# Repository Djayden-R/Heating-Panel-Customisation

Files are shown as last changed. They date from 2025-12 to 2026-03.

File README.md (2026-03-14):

# Heating-Panel-Customisation

This ESP-based device is an upgrade for a heating panel that lacks a thermostat, it will switch off the panel once it reaches the correct temperature. And all that in a formfactor of 5,8 x 2,9 x 3,3 cm (excl. the clip on the bottom).

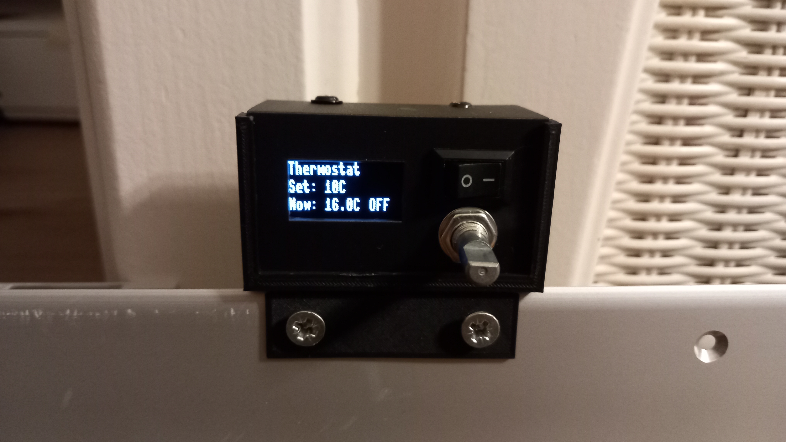
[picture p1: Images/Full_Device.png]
Device frontview


## Why did I make it?

My parents asked me if I could make something that would automatically turn off a heating panel if it reached a certain temperature. So that is what I set out to make.

## How does it work

The device consists of an ESP, a relay, and a temperature sensor. And for user input it also has a switch for turning the device on and off, a rotary encoder for setting the temperature, and an LCD showing the current temperature, set temperature and status. The wiring can be seen below.

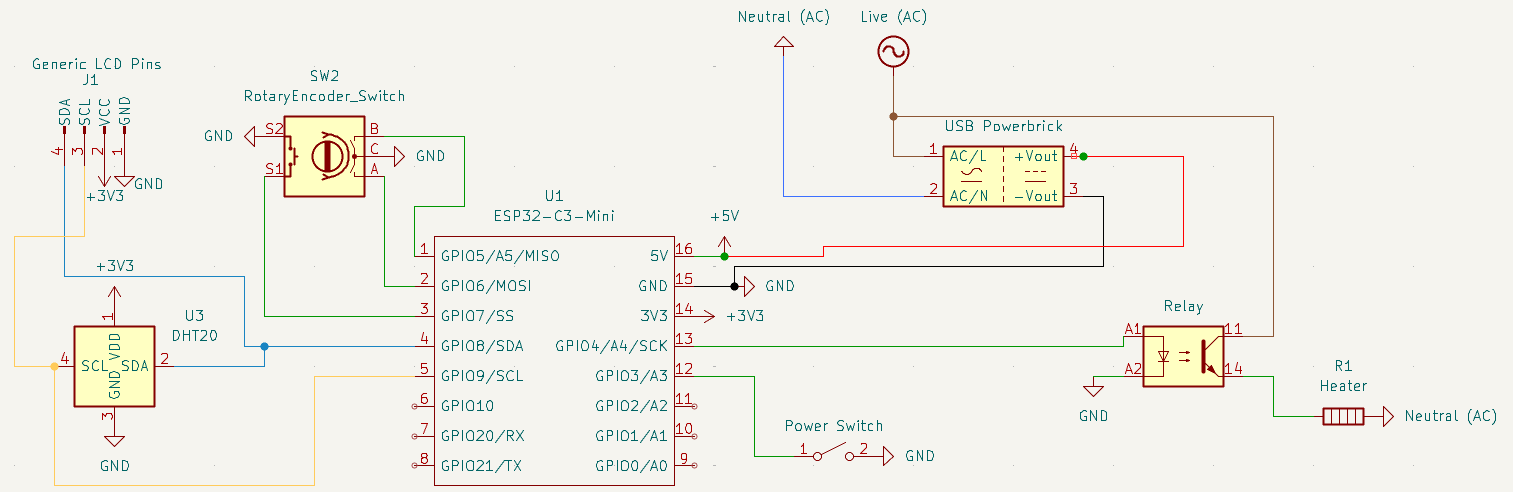
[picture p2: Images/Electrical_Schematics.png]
Wiring schematic


The ESP will sense the temperature in the room and turn on a relay that is connected to the heater if it is under the requested temperature. The ESP is powered from a USB powerbrick inside the heating panel. I also made a schematic with pictures of the components, but the wiring isn't that clear.

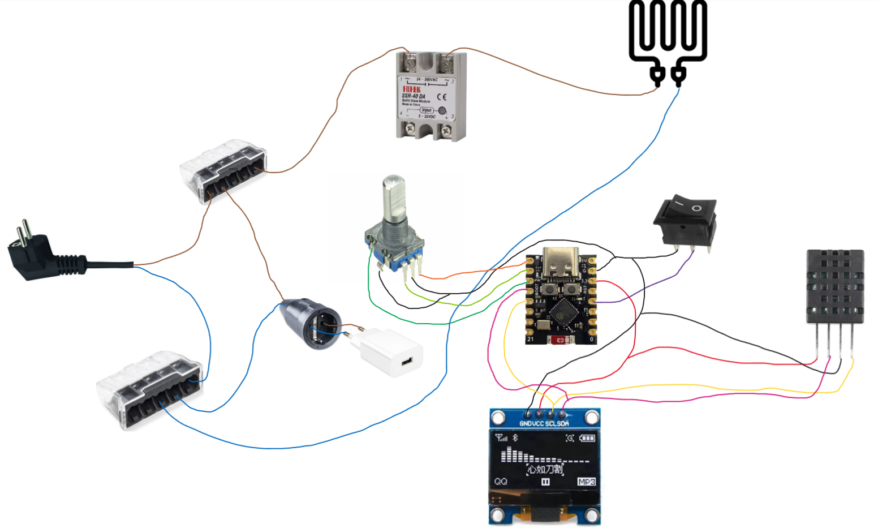
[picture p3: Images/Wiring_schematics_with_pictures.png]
Witing with pictures


The device's clip (see image below) can be placed on the ridge of the heating panel and be secured with bolts. There will have to be a hole drilled in the heating panel, through which the charging cable and cabel for the relay will be placed.

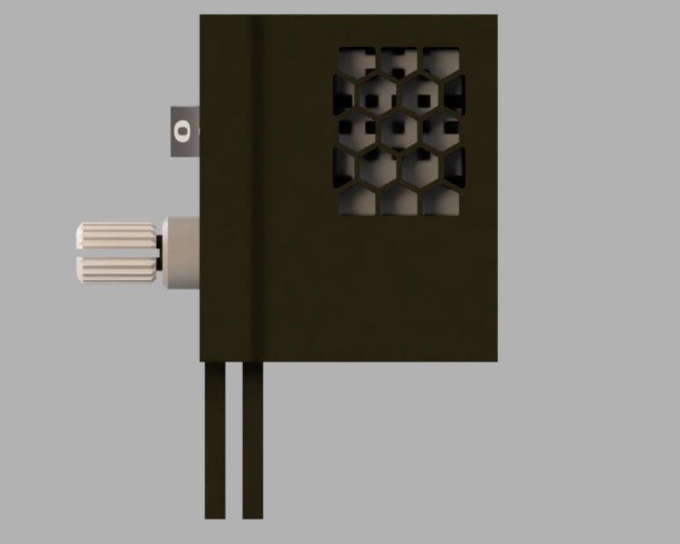
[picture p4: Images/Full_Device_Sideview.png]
Sideview of device

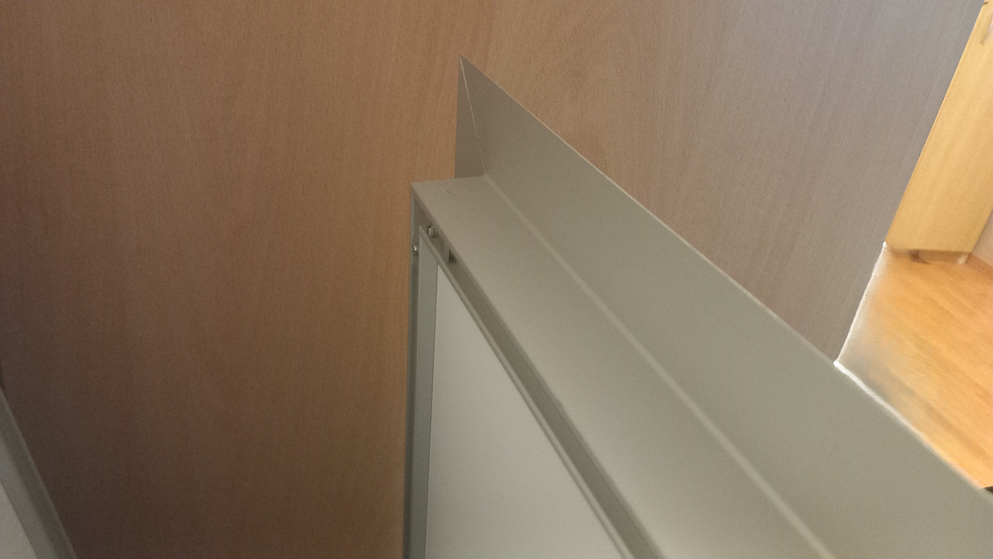
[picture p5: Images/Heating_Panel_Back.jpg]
Heating panel's ridge


I have made a short video demonstrating the finished project, you can find it [here](https://www.youtube.com/watch?v=DKDE-mrpqO4)

## How to assemble the device

Below is a GIF showing the process of putting the device together. Some steps are left out, like installing the outlet, connecting the ESP to it, connecting the relay inside the heating panel and to the ESP.

Assembly Instruction

## How to install firmware

The firmware is made for a micropython device, so if your device doesn't have micropython yet you should install that first.

To install the firmware use a program like Thonny IDE and upload all of the files ending in ```.py``` inside the Firmware folder and rename ```Device.py``` to main.py

The program should then just run on boot.

Also sidenote, the whole ```Device.py``` code is AI-generated, so if you are curious to see how it works you can take a look at it, but you won't find anything interesting.

## BOM

> USD prices are at the time of writing, use  a currency converter for more accurate USD prices

| Item | Description | Amount | Already owned | Cost (€) | Cost (US$) | URL | Image |
|---|---|---|---|---|---|-----|---|
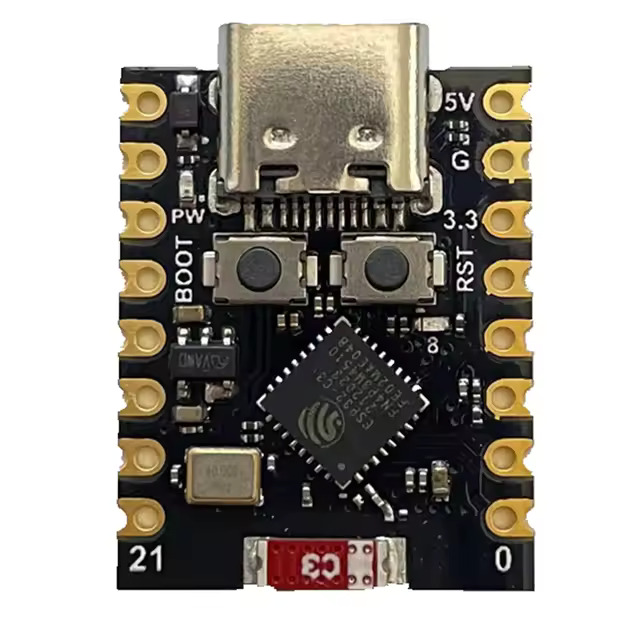
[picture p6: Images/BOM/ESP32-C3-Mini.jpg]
ESP32 C3 Mini
| ESP32 C3 Mini | ESP module | 1 | no | 2.99 | 3.52 | <https://nl.aliexpress.com/item/1005010612626337.html> |  |
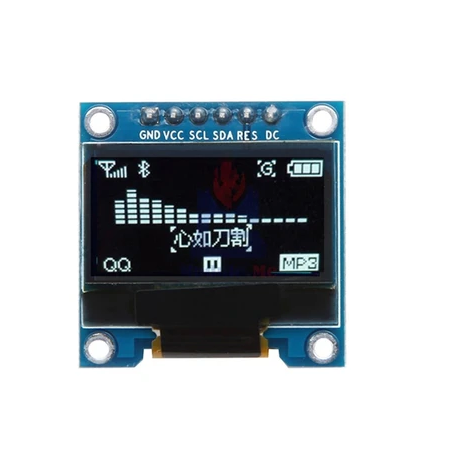
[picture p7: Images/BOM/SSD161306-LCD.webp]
LCD Screen
| SSD1306 LCD | 4 pin serial LCD | 1 | no | 2.10 | 2.47 | <https://nl.aliexpress.com/item/1005010446208996.html> |  |
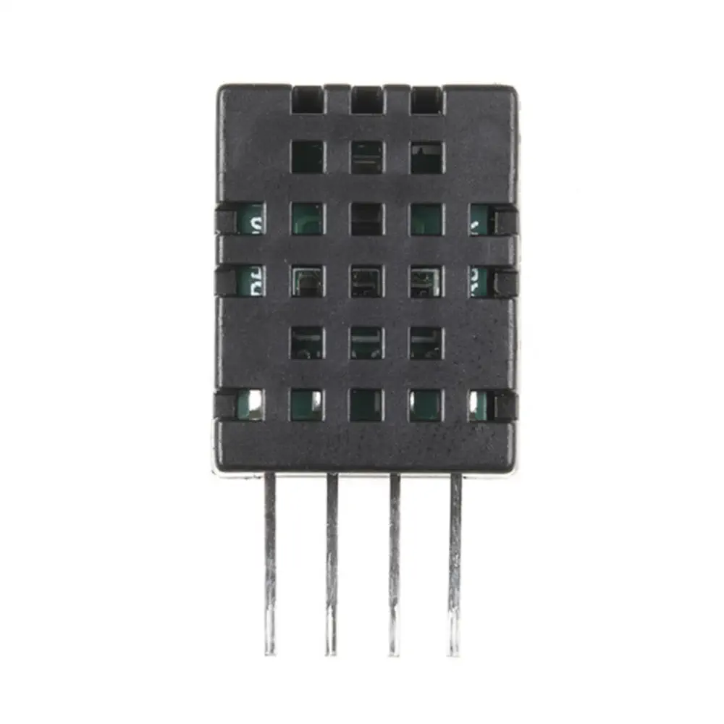
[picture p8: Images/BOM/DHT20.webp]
DHT20
| DHT20 Sensor | Temperature and humidity sensor | 1 | no | 1.16 | 1.37 | <https://nl.aliexpress.com/item/1005006337702724.html> |  |
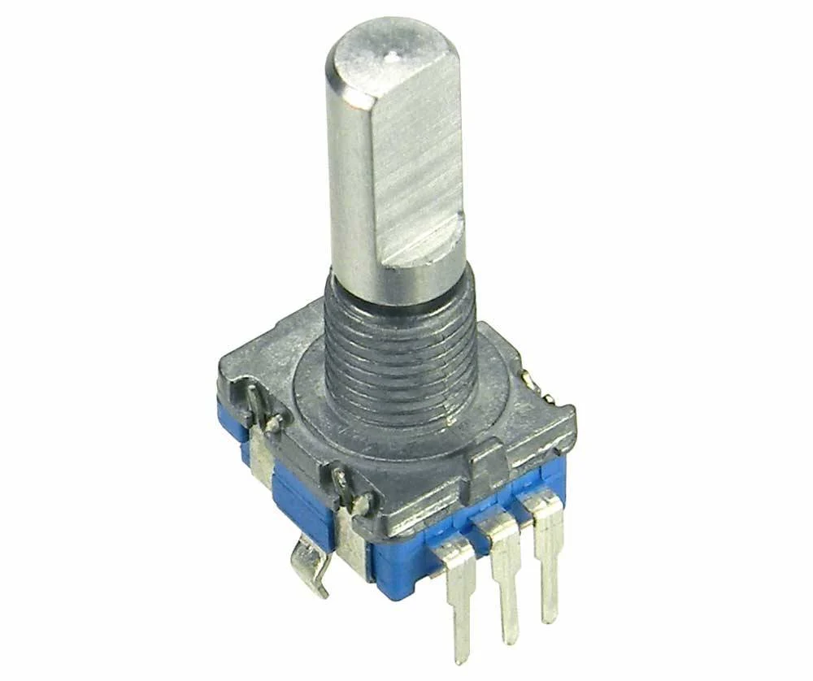
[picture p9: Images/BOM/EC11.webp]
EC11
| EC11 Encoder | Rotary encoder with push button | 1 | no | 1.27 | 1.50 | <https://nl.aliexpress.com/item/1005008773438800.html> |  |
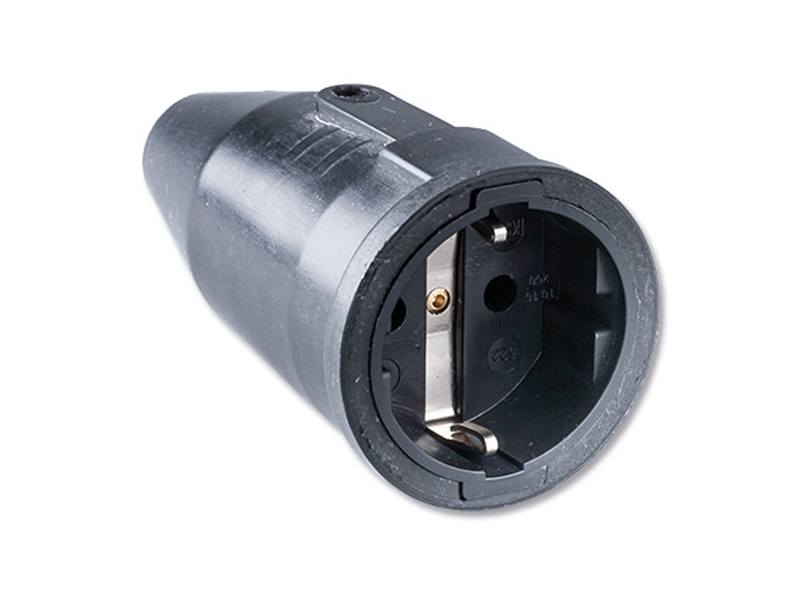
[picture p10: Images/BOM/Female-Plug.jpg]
Female Plug
| Female plug | Internal plug to power ESP | 1 | no | 1.69 | 1.99 | <https://www.gamma.nl/assortiment/handson-contrastekker-zwart/p/B275982> |  |
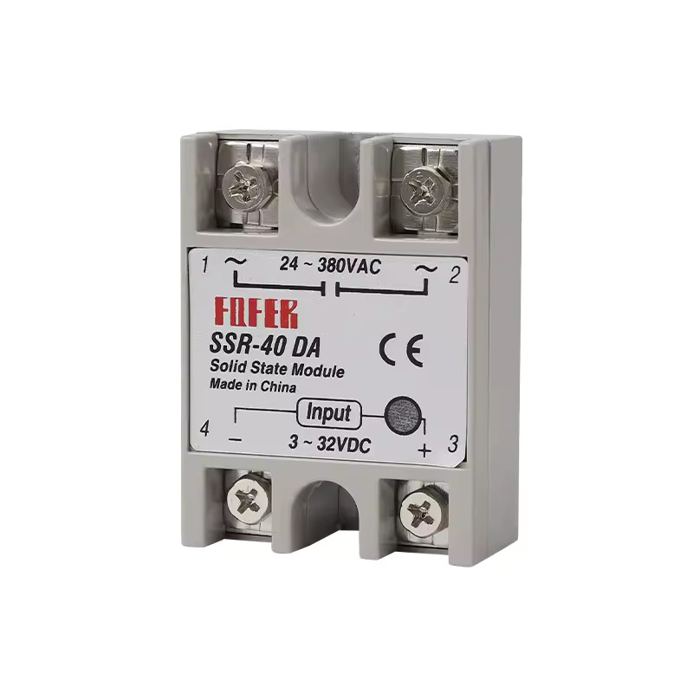
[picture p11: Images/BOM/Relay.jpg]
Relay
| Relay (230 AC 25A) | Solid-state relay (3V trigger) | 1 | no | 3.37 | 3.97 | <https://nl.aliexpress.com/item/1005006782419296.html> |  |
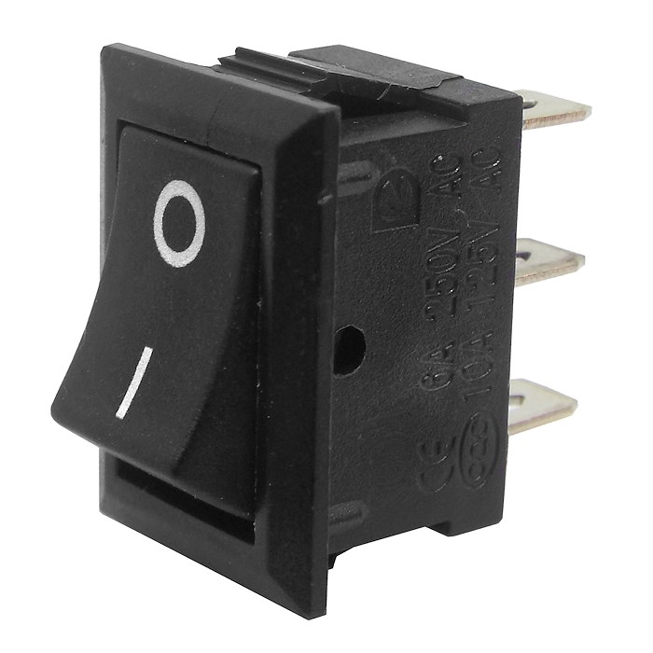
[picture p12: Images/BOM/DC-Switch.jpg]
DC Switch
| DC Rocker Switch | Simple small DC switch | 1 | yes | - | - | - |  |
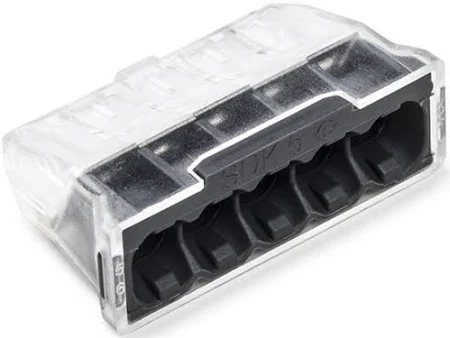
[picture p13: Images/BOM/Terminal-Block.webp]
Terminal Block
| Terminal block | Like a WAGO, but cheap | 2 | yes | - | - | - |  |
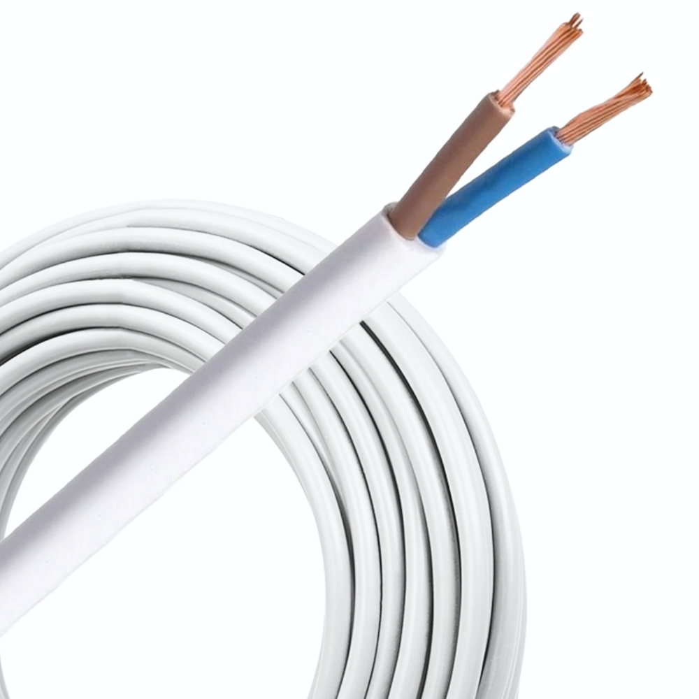
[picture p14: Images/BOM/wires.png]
Wires
| AC and DC wires | ~2.5m AC + DC wiring | - | yes | - | - | - |  |
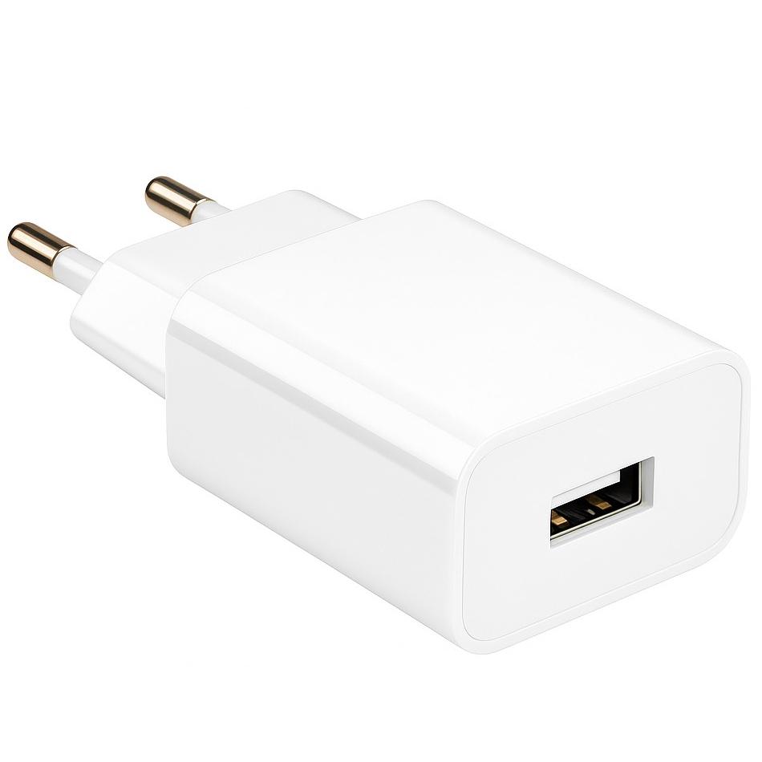
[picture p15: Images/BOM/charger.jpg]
Charger
| Phone charger | ESP power supply | 1 | yes | - | - | - |  |

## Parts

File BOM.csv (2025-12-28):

Item | Description | Amount | Cost (€) | Cost (US$) | Already owned | URL
ESP32 C3 Mini | ESP module | 1 | 2.99 | 3.52 | no | https://nl.aliexpress.com/item/1005010612626337.html
SSD1306 LCD | 4 pin serial LCD | 1 | 2.10 | 2.47 | no | https://nl.aliexpress.com/item/1005010446208996.html
DHT20 Sensor | Temperature and humidity sensor | 1 | 1.16 | 1.37 | no | https://nl.aliexpress.com/item/1005006337702724.html
EC11 Encoder | Rotary encoder with push button | 1 | 1.27 | 1.50 | no | https://nl.aliexpress.com/item/1005008773438800.html
Female plug | An internal plug to provide power to the ESP | 1 | 1.69 | 1.99 | no | https://www.gamma.nl/assortiment/handson-contrastekker-zwart/p/B275982
Relay (230 AC 25 Amp) | A solid-state relay that can be switch with 3 volt | 1 | 3.37 | 3.97 | no | https://nl.aliexpress.com/item/1005006782419296.html
DC Rocker Switch | Simple small DC switch | 1 | - | - | yes | -
Terminal block | Like a WAGO, but cheap | 2 | - | - | yes | -
AC and DC wires | About 2,5 meter of wires for AC power and some wire for DC | - | - | - | yes | -
Phone charger | The powersupply for the ESP (don't forget a USB-C cable) | 1 | - | - | yes | -

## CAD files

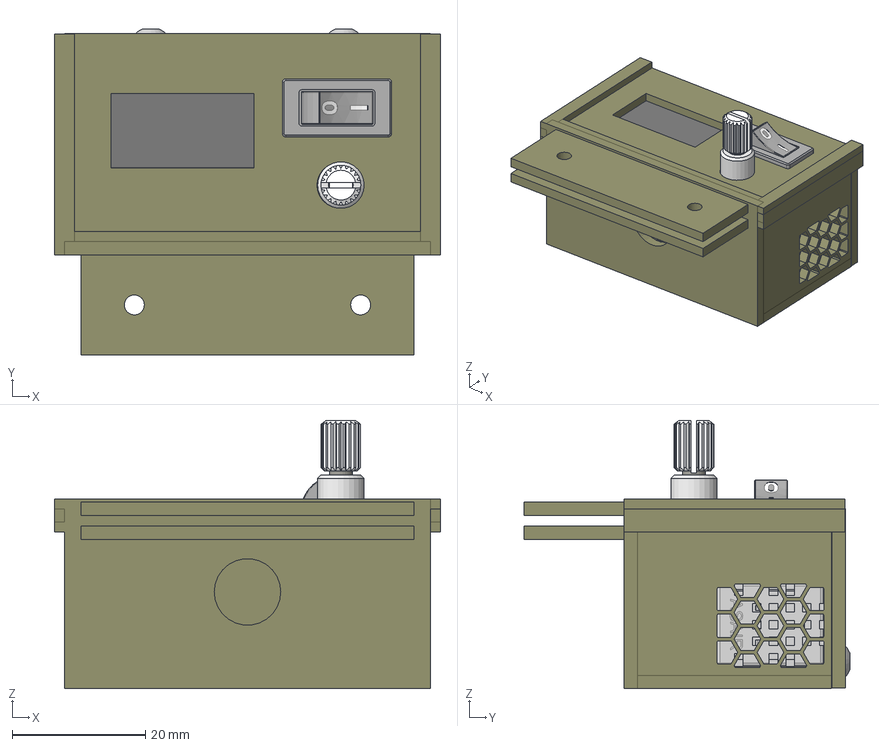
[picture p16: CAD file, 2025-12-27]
CAD/Full device.step
58.0 x 48.9 x 40.3 mm
SFS-EN ISO 7380-2 - M2 x 4 Steel 4.6 Plain x 4
SFS-EN ISO 7380-2 - M3 x 6 Steel 4.6 Plain x 2

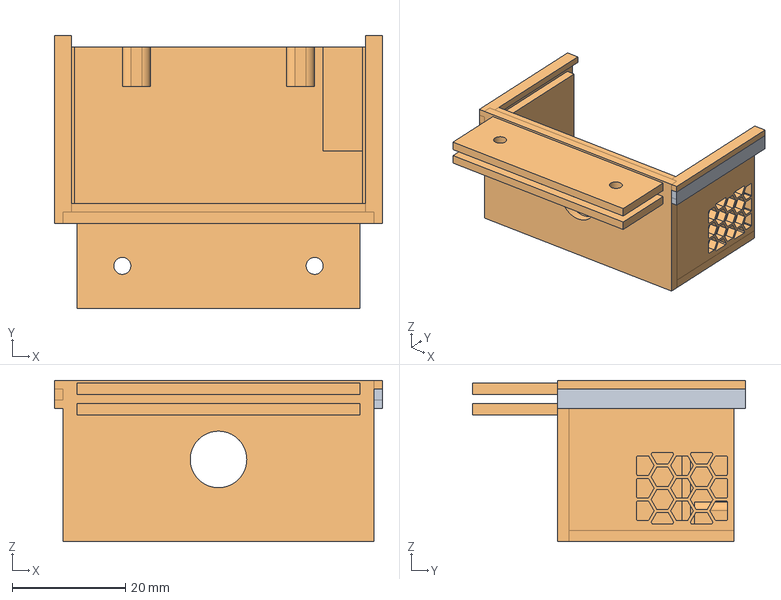
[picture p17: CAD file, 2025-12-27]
CAD/Main body.step
58.0 x 48.2 x 28.5 mm

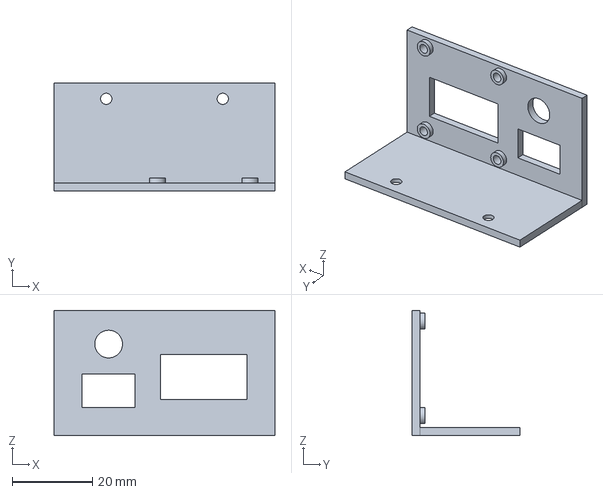
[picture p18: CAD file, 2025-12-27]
CAD/Front panel.step
55.0 x 27.0 x 31.2 mm

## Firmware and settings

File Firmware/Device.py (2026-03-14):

from machine import I2C, Pin
from ssd1306 import SSD1306_I2C
from dht20 import DHT20
from micropython_rotary_encoder import RotaryEncoderRP2, RotaryEncoderEvent
from time import sleep

# -----------------------------
# Encoder
# -----------------------------
encoder_value = 20

MIN_TEMP = 5
MAX_TEMP = 30

en_pin_clk = Pin(6, Pin.IN, Pin.PULL_UP)
en_pin_dt = Pin(5, Pin.IN, Pin.PULL_UP)
en_pin_sw = Pin(7, Pin.IN, Pin.PULL_UP)

encoder = RotaryEncoderRP2(
    en_pin_clk,
    en_pin_dt,
    en_pin_sw,
    encoder_step=2,   # helpt tegen overslaan
    half_step=True    # nodig voor veel KY-040 encoders
)

def turn_right():
    global encoder_value
    encoder_value += 1
    if encoder_value > MAX_TEMP:
        encoder_value = MAX_TEMP

def turn_left():
    global encoder_value
    encoder_value -= 1
    if encoder_value < MIN_TEMP:
        encoder_value = MIN_TEMP

encoder.on(RotaryEncoderEvent.TURN_RIGHT, turn_right)
encoder.on(RotaryEncoderEvent.TURN_LEFT, turn_left)
# -----------------------------
# I2C devices
# -----------------------------
i2c = I2C(sda=Pin(8), scl=Pin(9))
oled = SSD1306_I2C(128, 32, i2c)
dht20 = DHT20(0x38, i2c)
# -----------------------------
# Inputs / outputs
# -----------------------------
switch = Pin(4, Pin.IN, Pin.PULL_UP)
relay = Pin(21, Pin.OUT)
# -----------------------------
# Screen
# -----------------------------
def update_screen(set_temp, current_temp, humidity, status_message):
    oled.fill(0)
    oled.text("Thermostat", 0, 0)
    oled.text("Set:", 0, 10)
    oled.text(str(set_temp) + "C", 40, 10)
    oled.text("Now:", 0, 20)
    oled.text(str(round(current_temp,1)) + "C", 40, 20)
    oled.text(status_message, 90, 20)
    oled.show()


# -----------------------------
# Sensor
# -----------------------------
def get_temp_and_humidity():
    measurements = dht20.measurements
    temperature = measurements['t']
    humidity = measurements['rh']
    return temperature, humidity


# -----------------------------
# Main logic
# -----------------------------
HYSTERESIS = 0.3

def main():
    system_on = False
    while True:
        # Let encoder process events
        encoder.raw_tick()

        # SWITCH ON
        if switch.value() == 0:

            if not system_on:
                oled.poweron()
                system_on = True

            current_temperature, humidity = get_temp_and_humidity()
            set_temperature = encoder_value

            if current_temperature < set_temperature - HYSTERESIS:
                relay.on()
                status = "HEAT"

            elif current_temperature > set_temperature + HYSTERESIS:
                relay.off()
                status = "OFF"

            else:
                status = "HEAT" if relay.value() else "OFF"

            update_screen(set_temperature, current_temperature, humidity, status)

            sleep(0.1)

        # SWITCH OFF
        else:
            if system_on:
                relay.off()
                oled.fill(0)
                oled.text("Thermostat", 0, 0)
                oled.text("Turning off...", 0, 16)
                oled.show()
                sleep(2)
                oled.poweroff()
                system_on = False

            sleep(0.1)


if __name__ == "__main__":
    main()

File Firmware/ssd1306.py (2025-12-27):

# MicroPython SSD1306 OLED driver, I2C and SPI interfaces

# MIT License (MIT)
# Copyright (c) 2018 Stefan Lehmann
# https://opensource.org/licenses/MIT

# Documentation:
#   https://github.com/stlehmann/micropython-ssd1306

from micropython import const
import framebuf


# register definitions
SET_CONTRAST = const(0x81)
SET_ENTIRE_ON = const(0xA4)
SET_NORM_INV = const(0xA6)
SET_DISP = const(0xAE)
SET_MEM_ADDR = const(0x20)
SET_COL_ADDR = const(0x21)
SET_PAGE_ADDR = const(0x22)
SET_DISP_START_LINE = const(0x40)
SET_SEG_REMAP = const(0xA0)
SET_MUX_RATIO = const(0xA8)
SET_COM_OUT_DIR = const(0xC0)
SET_DISP_OFFSET = const(0xD3)
SET_COM_PIN_CFG = const(0xDA)
SET_DISP_CLK_DIV = const(0xD5)
SET_PRECHARGE = const(0xD9)
SET_VCOM_DESEL = const(0xDB)
SET_CHARGE_PUMP = const(0x8D)

# Subclassing FrameBuffer provides support for graphics primitives
# http://docs.micropython.org/en/latest/pyboard/library/framebuf.html
class SSD1306(framebuf.FrameBuffer):
    def __init__(self, width, height, external_vcc):
        self.width = width
        self.height = height
        self.external_vcc = external_vcc
        self.pages = self.height // 8
        self.buffer = bytearray(self.pages * self.width)
        super().__init__(self.buffer, self.width, self.height, framebuf.MONO_VLSB)
        self.init_display()

    def init_display(self):
        for cmd in (
            SET_DISP | 0x00,  # off
            # address setting
            SET_MEM_ADDR,
            0x00,  # horizontal
            # resolution and layout
            SET_DISP_START_LINE | 0x00,
            SET_SEG_REMAP | 0x01,  # column addr 127 mapped to SEG0
            SET_MUX_RATIO,
            self.height - 1,
            SET_COM_OUT_DIR | 0x08,  # scan from COM[N] to COM0
            SET_DISP_OFFSET,
            0x00,
            SET_COM_PIN_CFG,
            0x02 if self.width > 2 * self.height else 0x12,
            # timing and driving scheme
            SET_DISP_CLK_DIV,
            0x80,
            SET_PRECHARGE,
            0x22 if self.external_vcc else 0xF1,
            SET_VCOM_DESEL,
            0x30,  # 0.83*Vcc
            # display
            SET_CONTRAST,
            0xFF,  # maximum
            SET_ENTIRE_ON,  # output follows RAM contents
            SET_NORM_INV,  # not inverted
            # charge pump
            SET_CHARGE_PUMP,
            0x10 if self.external_vcc else 0x14,
            SET_DISP | 0x01,
        ):  # on
            self.write_cmd(cmd)
        self.fill(0)
        self.show()

    def poweroff(self):
        self.write_cmd(SET_DISP | 0x00)

    def poweron(self):
        self.write_cmd(SET_DISP | 0x01)

    def contrast(self, contrast):
        self.write_cmd(SET_CONTRAST)
        self.write_cmd(contrast)

    def invert(self, invert):
        self.write_cmd(SET_NORM_INV | (invert & 1))

    def show(self):
        x0 = 0
        x1 = self.width - 1
        if self.width == 64:
            # displays with width of 64 pixels are shifted by 32
            x0 += 32
            x1 += 32
        self.write_cmd(SET_COL_ADDR)
        self.write_cmd(x0)
        self.write_cmd(x1)
        self.write_cmd(SET_PAGE_ADDR)
        self.write_cmd(0)
        self.write_cmd(self.pages - 1)
        self.write_data(self.buffer)


class SSD1306_I2C(SSD1306):
    def __init__(self, width, height, i2c, addr=0x3C, external_vcc=False):
        self.i2c = i2c
        self.addr = addr
        self.temp = bytearray(2)
        self.write_list = [b"\x40", None]  # Co=0, D/C#=1
        super().__init__(width, height, external_vcc)

    def write_cmd(self, cmd):
        self.temp[0] = 0x80  # Co=1, D/C#=0
        self.temp[1] = cmd
        self.i2c.writeto(self.addr, self.temp)

    def write_data(self, buf):
        self.write_list[1] = buf
        self.i2c.writevto(self.addr, self.write_list)


class SSD1306_SPI(SSD1306):
    def __init__(self, width, height, spi, dc, res, cs, external_vcc=False):
        self.rate = 10 * 1024 * 1024
        dc.init(dc.OUT, value=0)
        res.init(res.OUT, value=0)
        cs.init(cs.OUT, value=1)
        self.spi = spi
        self.dc = dc
        self.res = res
        self.cs = cs
        import time

        self.res(1)
        time.sleep_ms(1)
        self.res(0)
        time.sleep_ms(10)
        self.res(1)
        super().__init__(width, height, external_vcc)

    def write_cmd(self, cmd):
        self.spi.init(baudrate=self.rate, polarity=0, phase=0)
        self.cs(1)
        self.dc(0)
        self.cs(0)
        self.spi.write(bytearray([cmd]))
        self.cs(1)

    def write_data(self, buf):
        self.spi.init(baudrate=self.rate, polarity=0, phase=0)
        self.cs(1)
        self.dc(1)
        self.cs(0)
        self.spi.write(buf)
        self.cs(1)

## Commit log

2025-12-26 add more images of device
2025-12-27 add 3D models
    [Front panel.step, Full device.step, Main body.step]
2025-12-27 add device wiring
    [Device wiring.kicad_sch]
2025-12-27 add GIF showing assembly
2025-12-27 update wiring cschematics to remove unnecessary resistor
2025-12-27 add code for device
2025-12-27 add BOM to README
2025-12-27 add images for BOM table
2025-12-28 add seperate BOM
    [BOM.csv]
2026-01-03 update wiring schematics
2026-01-03 Add wiring schematics with pictures and add to README.md
